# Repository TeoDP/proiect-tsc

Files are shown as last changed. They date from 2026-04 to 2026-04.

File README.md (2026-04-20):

# InkTime Smartwatch PCB

## General Description

This project involves the development of a PCB for an open-source smartwatch named InkTime, based on the nRF52840 microcontroller. The primary goal was to integrate all necessary components, including processing, sensors, power management, and user interface, onto a compact board that adheres to both electrical constraints and the mechanical limitations of the device housing.

The design was created using Fusion 360 Electronics, following the provided electrical schematics and laboratory layout guidelines. Significant emphasis was placed on precise routing, ground plane integrity, and component density within a limited footprint.

## Hardware Components

The system's core components include:

    - nRF52840: Main microcontroller with BLE capabilities.

    - IMU: Accelerometer and Gyroscope for motion tracking.

    - E-Paper Display: Ultra-low-power visual interface.

    - PMIC: Power Management IC for system stability.

    - Li-Po Battery: System power source.

    - USB-C: Interface for charging and power supply.

    - Haptic Motor: Vibration feedback.

Component Connectivity:

    - IMU: Connected to the MCU via I2C (SDA, SCL).

    - Display: Connected via SPI (MOSI, SCK, CS, DC, RST).

    - PMIC: Manages the entire system's power distribution.

    - USB-C: Connected directly to the charging circuitry.

    - Haptic Motor: Controlled via standard GPIO.

## Hardware Functionality

The system is centered around the nRF52840, which manages all peripherals and communications. Communication with sensors and the display is handled through standard interfaces:

    - SPI: Utilized for the display to ensure higher data transfer speeds.

    - I2C: Utilized for the IMU for simple and efficient sensor polling.

The system is powered by a Li-Po battery via a PMIC circuit that provides:

    - Voltage stabilization.

    - Overcharge/discharge protection.

    - Power distribution across all subsystems.

USB-C serves a dual purpose for battery charging and direct system power. The haptic motor provides tactile feedback and is managed by a dedicated GPIO pin.

### Estimated Consumption:

    - MCU: Low consumption in sleep mode, higher during active BLE transmission.

    - E-Paper Display: Negligible consumption (only draws power during screen updates).

    - IMU: Low power consumption over I2C.

## PCB Layout

### The PCB was designed using a 2-layer stackup:

    - Top Layer: Primary component placement and signal routing.

    - Bottom Layer: Supplementary routing and dedicated ground plane.

### Design Rules Applied:

    - Power Traces: Increased width for power lines (e.g., 3V3, VBUS).

    - Signal Traces: Minimum width of 0.15 mm.

    - Geometry: Avoided 90-degree angles to prevent signal reflection and manufacturing issues.

### Antenna Design:

    - Copper-free zone maintained directly beneath the antenna.

    - No routing allowed in the antenna keepout area to ensure signal integrity.

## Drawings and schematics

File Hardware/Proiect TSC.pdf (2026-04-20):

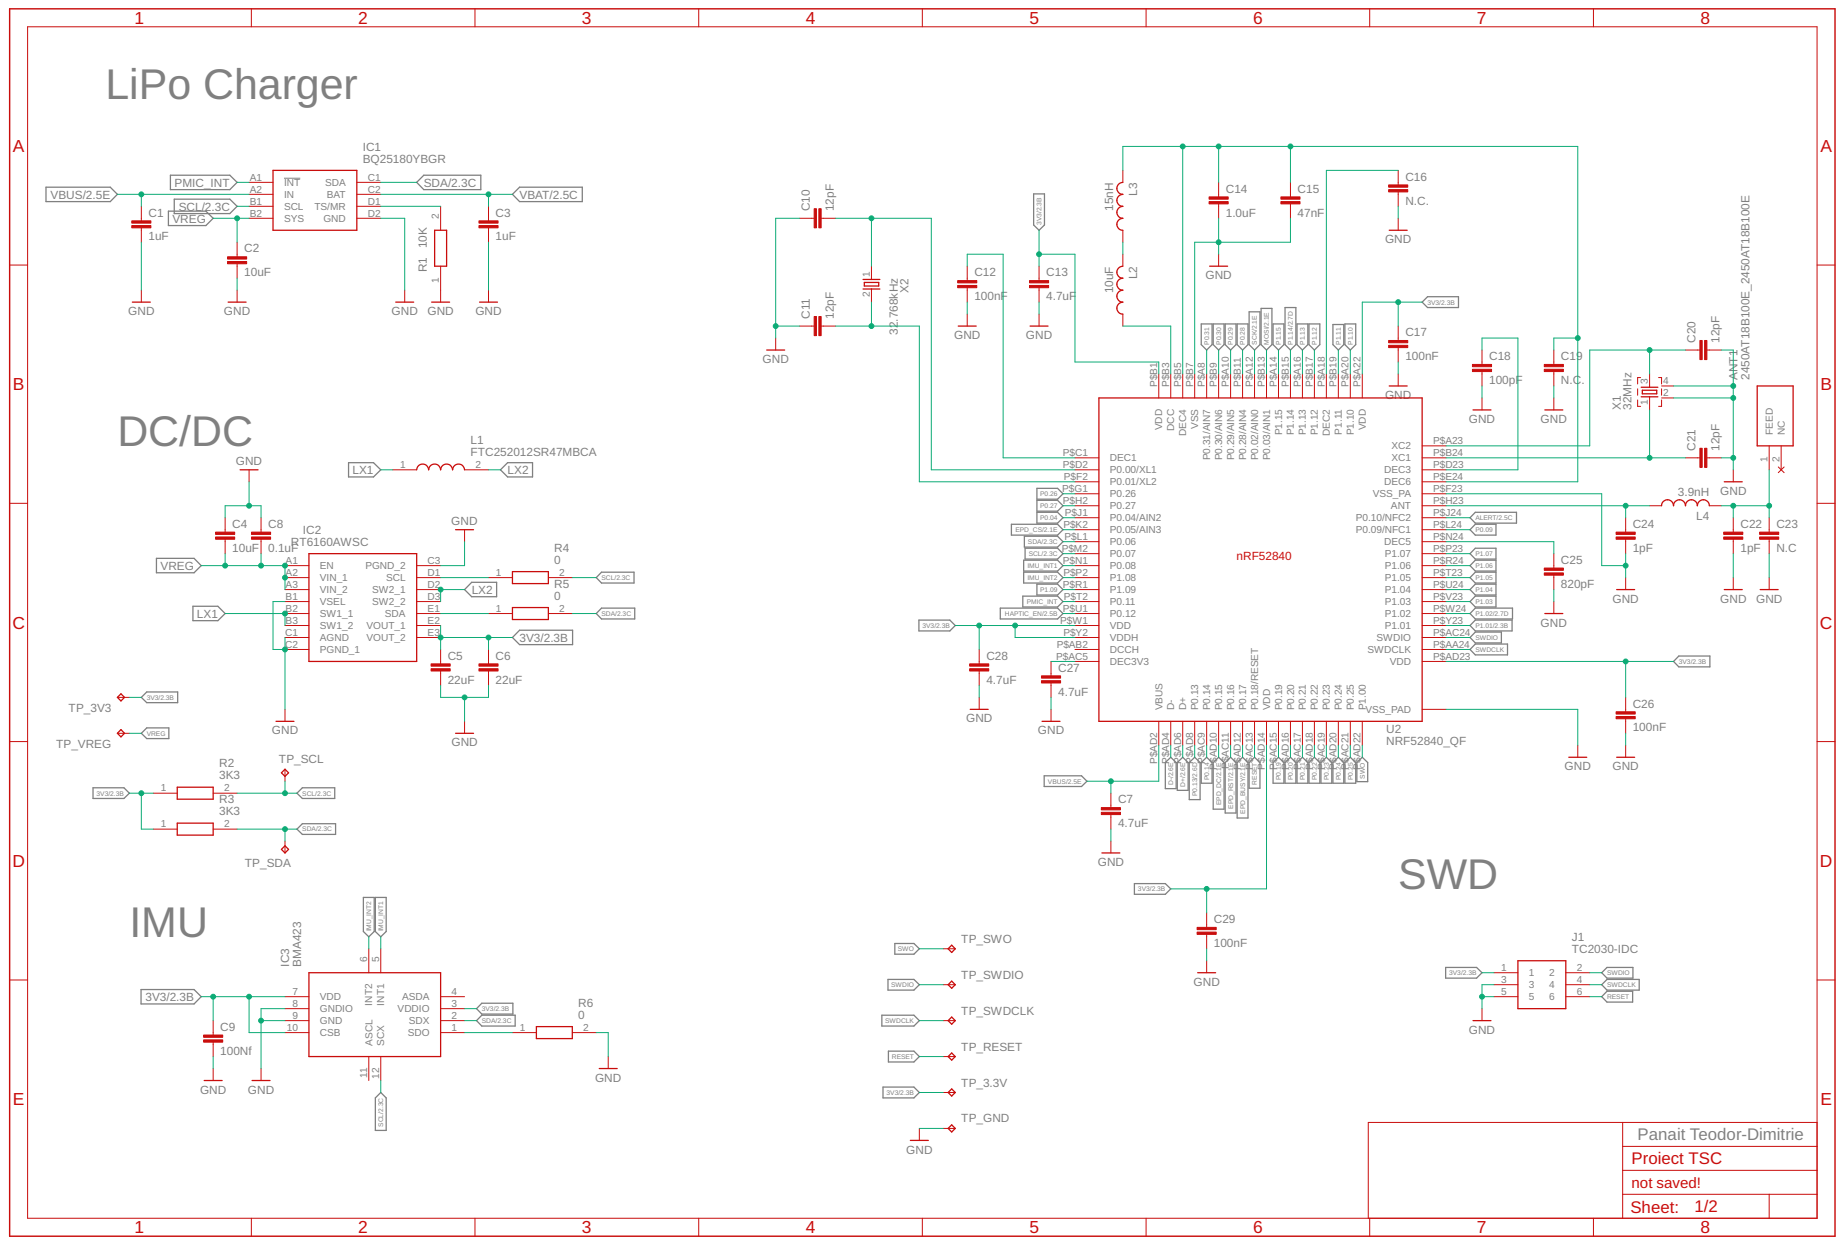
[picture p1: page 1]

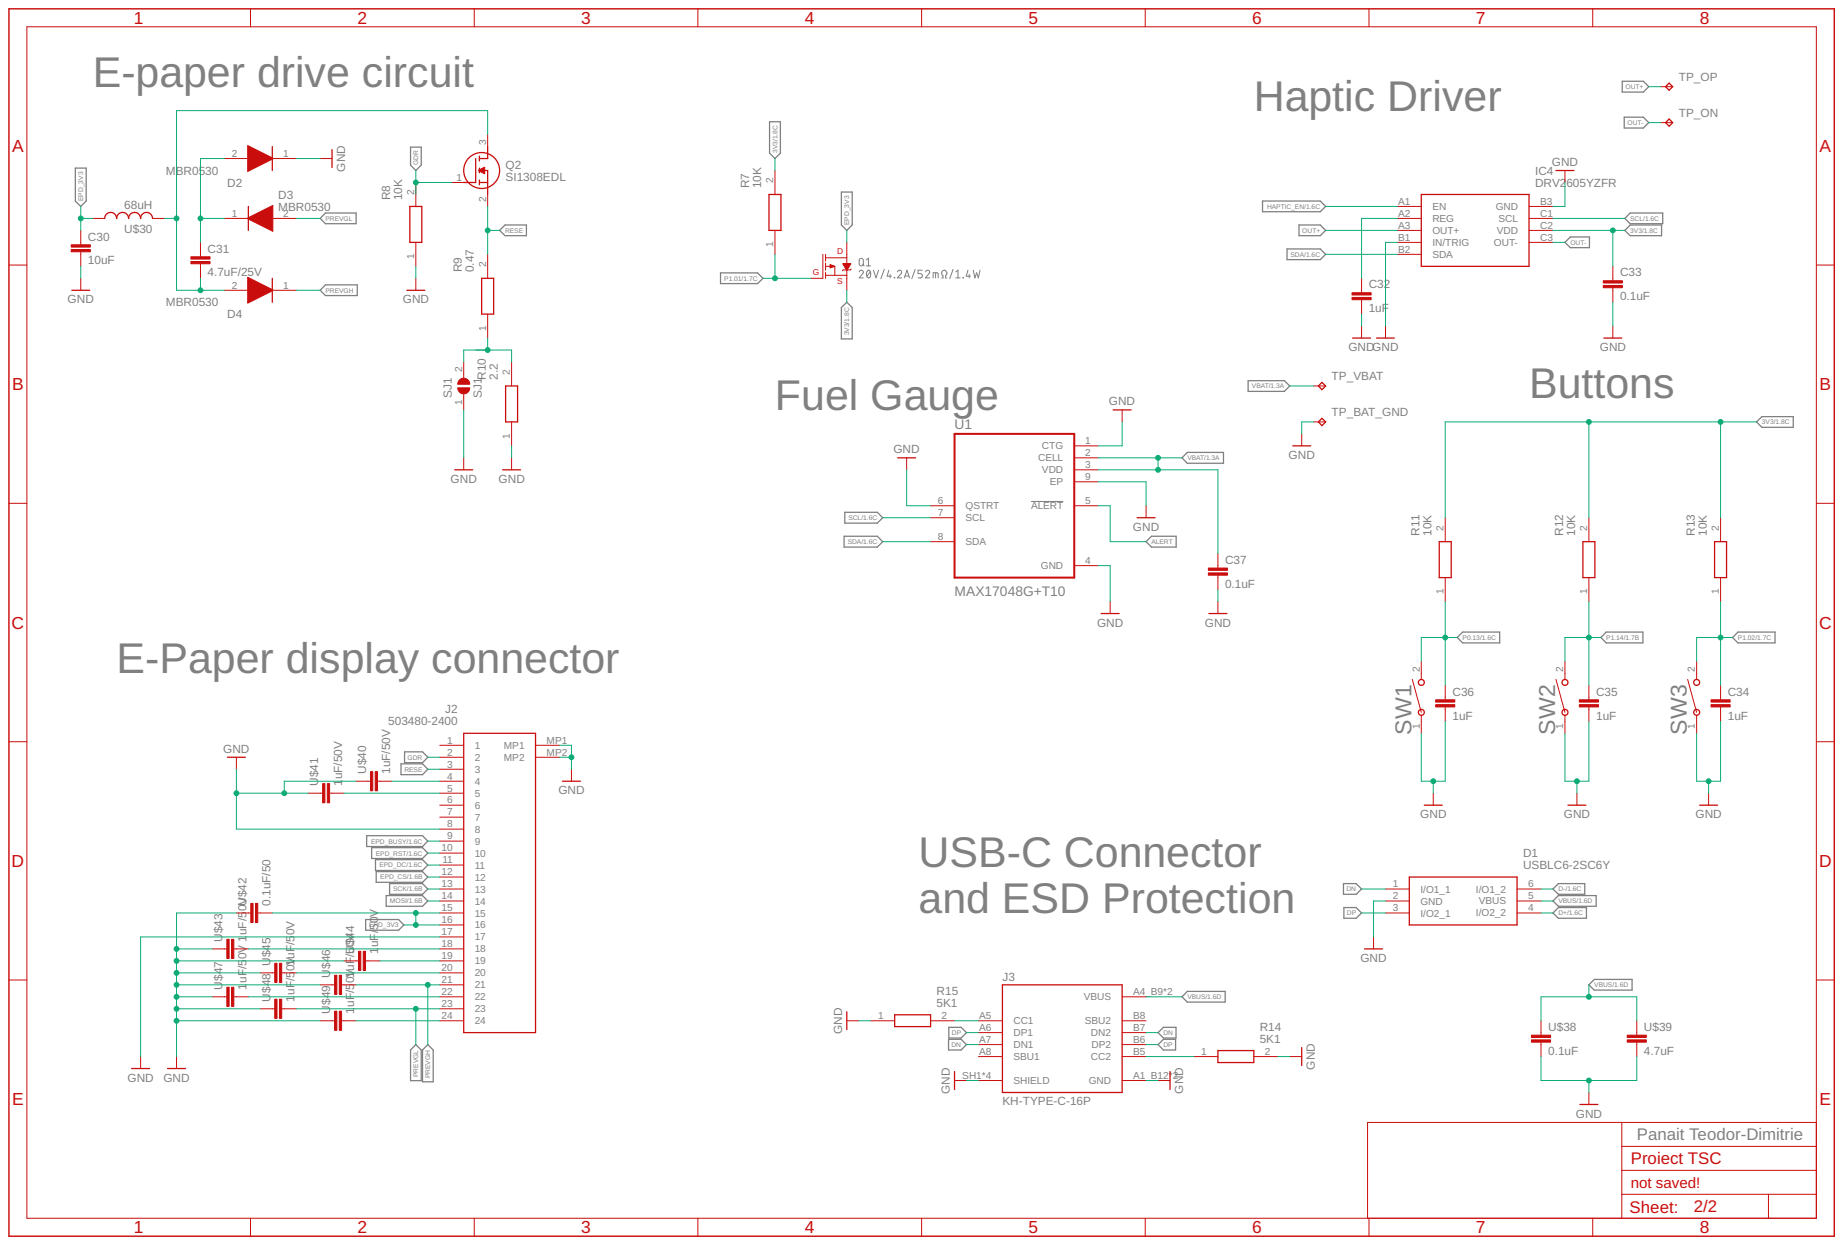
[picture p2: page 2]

EPD_3V3 | 16

18
19

23
24

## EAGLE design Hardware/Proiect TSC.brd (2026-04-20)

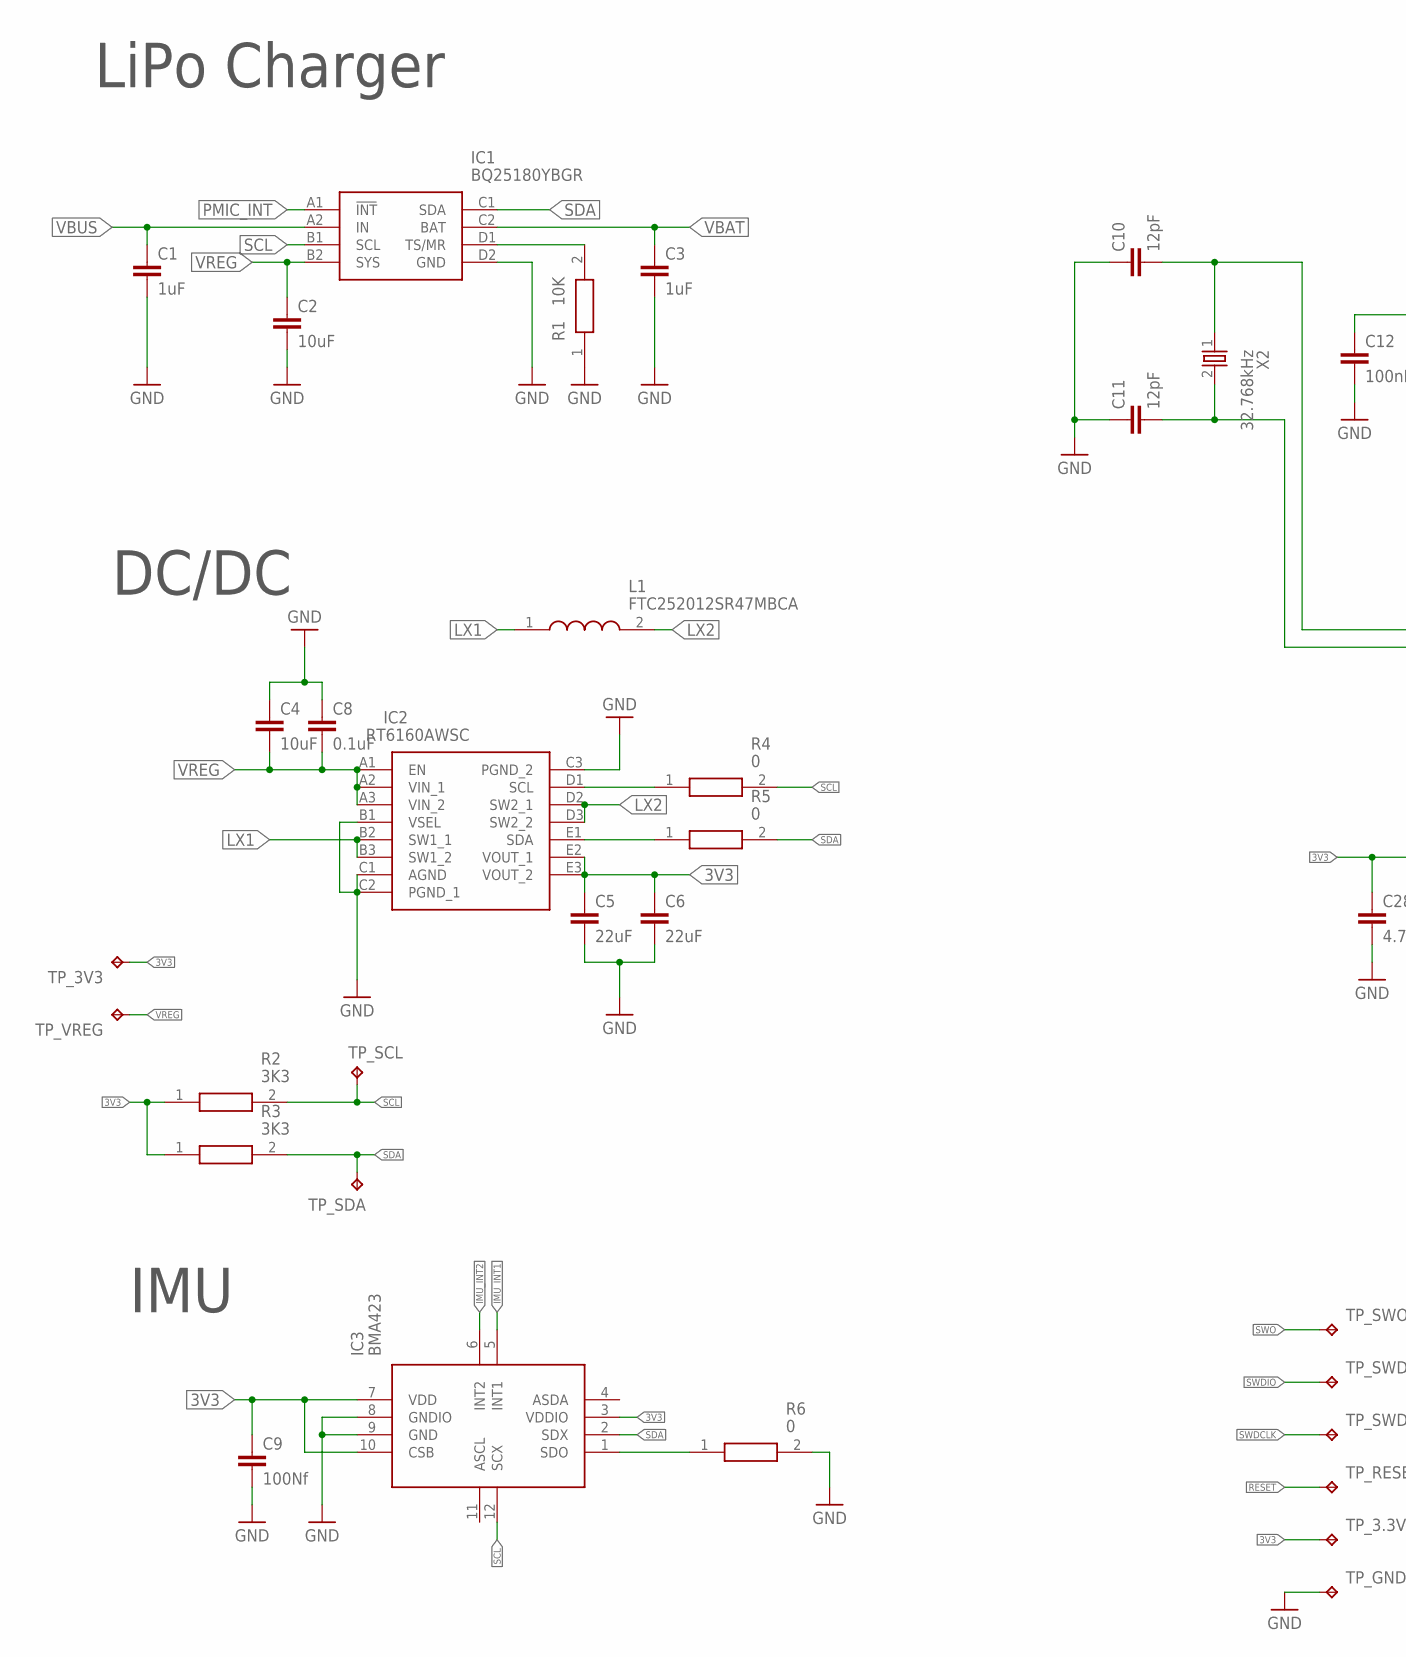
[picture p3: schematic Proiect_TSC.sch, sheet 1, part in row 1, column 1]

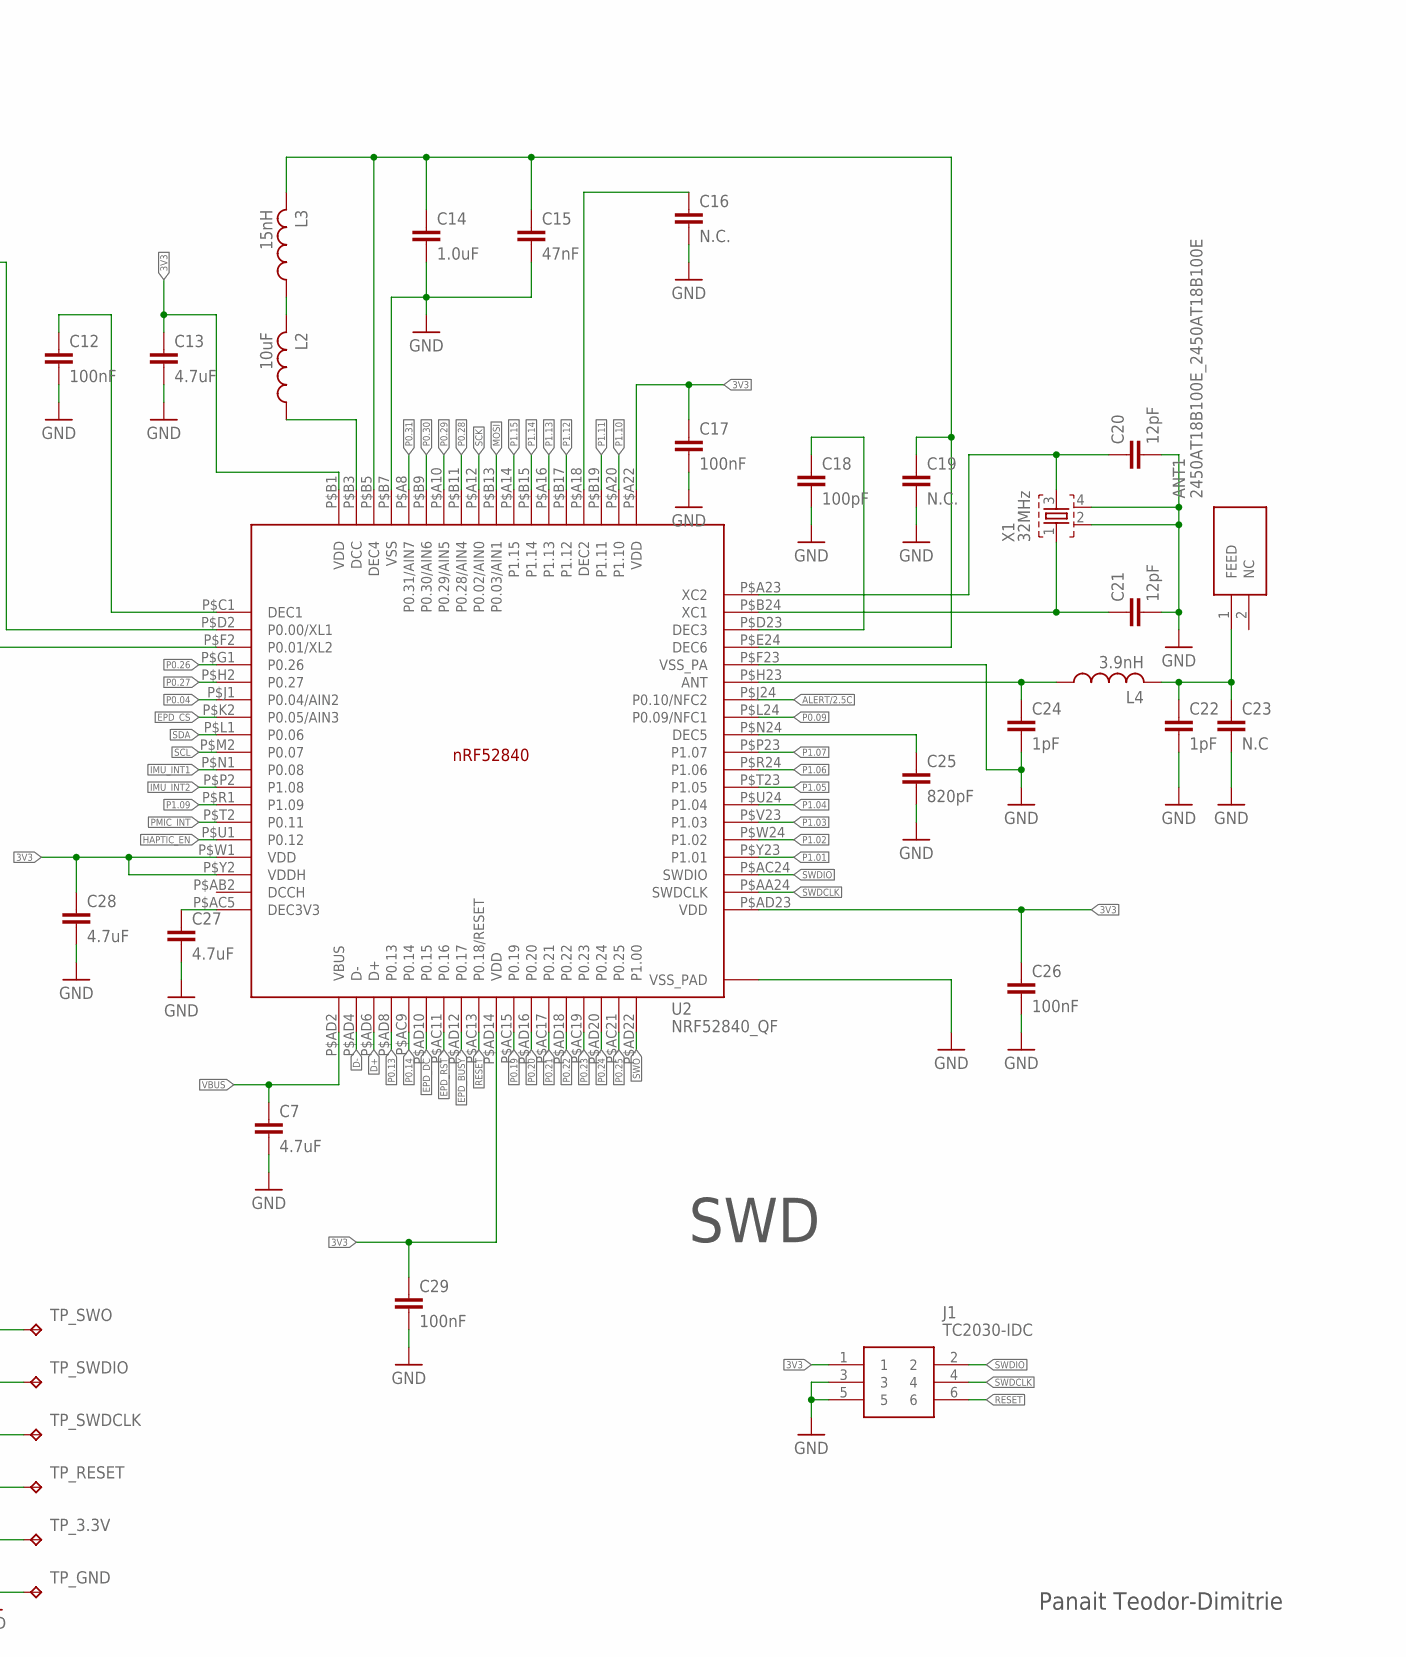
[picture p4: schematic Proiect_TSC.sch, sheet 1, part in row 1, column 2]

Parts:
ANT1: 2450AT18B100E_2450AT18B100E; 2450AT18B100E_ANTC3216X140N
C1, C3: 1uF; PERFECT_0402_0402
C2, C4: 10uF; PERFECT_0402_0402
C5, C6: 22uF; PERFECT_0402_0402
C7: 4.7uF; PERFECT_0402_0402
C8: 0.1uF; NORDIC_NRF_3_RESC0201_L
C9: 100Nf; NORDIC_NRF_3_RESC0201_L
C10, C11, C20, C21: 12pF; NORDIC_NRF_3_RESC0201_L
C12, C17, C26, C29: 100nF; NORDIC_NRF_3_RESC0201_L
C13, C27, C28: 4.7uF; NORDIC_NRF_3_RESC0402_L
C14: 1.0uF; NORDIC_NRF_3_RESC0402_L
C15: 47nF; NORDIC_NRF_3_RESC0201_L
C16, C19: N.C.; NORDIC_NRF_3_RESC0201_L
C18: 100pF; NORDIC_NRF_3_RESC0201_L
C22, C24: 1pF; NORDIC_NRF_3_RESC0201_L
C23: N.C; NORDIC_NRF_3_RESC0201_L
C25: 820pF; NORDIC_NRF_3_RESC0201_L
IC1: BQ25180YBGR; BQ25180YBGR_BGA8C40P2X4_100X155X50
IC2: RT6160AWSC; RT6160AWSC_BGA15C40P3X5_140X230X60
IC3: BMA423; BMA423_BMA423
J1: TC2030-IDC; TC2030-IDC_TC2030IDC
L1: FTC252012SR47MBCA; MLP2016SR47MT0S1_INDC2016X100N
L2: 10uF; NORDIC_NRF_2_RESC0201_L
L3: 15nH; NORDIC_NRF_2_RESC0201_L
L4: 3.9nH; NORDIC_NRF_2_RESC0201_L
R1: 10K; CPF0201D7K68C1_0201
R2, R3: 3K3; CPF0201D7K68C1_0201
R4, R5, R6: 0; CPF0201D7K68C1_0201
TP_3.3V, TP_3V3: HECTOR_WATCH_1_TPTP20R; HECTOR_WATCH_1_TP20R
TP_GND: HECTOR_WATCH_1_TPTP20R; HECTOR_WATCH_1_TP20R
TP_RESET: HECTOR_WATCH_1_TPTP20R; HECTOR_WATCH_1_TP20R
TP_SCL: HECTOR_WATCH_1_TPTP20R; HECTOR_WATCH_1_TP20R
TP_SDA: HECTOR_WATCH_1_TPTP20R; HECTOR_WATCH_1_TP20R
TP_SWDCLK: HECTOR_WATCH_1_TPTP20R; HECTOR_WATCH_1_TP20R
TP_SWDIO: HECTOR_WATCH_1_TPTP20R; HECTOR_WATCH_1_TP20R
TP_SWO: HECTOR_WATCH_1_TPTP20R; HECTOR_WATCH_1_TP20R
TP_VREG: HECTOR_WATCH_1_TPTP20R; HECTOR_WATCH_1_TP20R
U2: NRF52840_QF; NORDIC_NRF_4_AQFN50P700X700X85_HS-74N
X1: 32MHz; NORDIC_NRF_BT-XTAL_2016_N
X2: 32.768kHz; NORDIC_NRF_1_XTAL_3215_N

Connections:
3V3: C5.1, C6.1, C9.1, C13.1, C17.1, C26.1, C28.1, C29.1, IC2.E2 (VOUT_1), IC2.E3 (VOUT_2), IC3.3 (VDDIO), IC3.7 (VDD), IC3.10 (CSB), J1.1, R2.1, R3.1, TP_3.3V.TP, TP_3V3.TP, U2.P$A22 (VDD), U2.P$AD14 (VDD), U2.P$AD23 (VDD), U2.P$B1 (VDD), U2.P$W1 (VDD), U2.P$Y2 (VDDH); also elsewhere on the board
ALERT/2.5C: U2.P$J24 (P0.10/NFC2)
D+: U2.P$AD6 (D+); also elsewhere on the board
D-: U2.P$AD4 (D-); also elsewhere on the board
EPD_BUSY: U2.P$AD12 (P0.17); also elsewhere on the board
EPD_CS: U2.P$K2 (P0.05/AIN3); also elsewhere on the board
EPD_DC: U2.P$AD10 (P0.15); also elsewhere on the board
EPD_RST: U2.P$AC11 (P0.16); also elsewhere on the board
GND: C1.2, C2.2, C3.2, C4.1, C5.2, C6.2, C7.2, C8.1, C9.2, C10.1, C11.1, C12.2, C13.2, C14.2, C15.2, C16.2, C17.2, C18.2, C19.2, C20.2, C21.2, C22.2, C23.2, C24.2, C25.2, C26.2, C27.2, C28.2, C29.2, IC1.D2 (GND), IC2.B1 (VSEL), IC2.C1 (AGND), IC2.C2 (PGND_1), IC2.C3 (PGND_2), IC3.8 (GNDIO), IC3.9 (GND), J1.3, J1.5, R1.1, R6.2, TP_GND.TP, U2.P$74 (VSS_PAD), U2.P$75 (VSS_PAD), U2.P$76 (VSS_PAD), U2.P$77 (VSS_PAD), U2.P$78 (VSS_PAD), U2.P$79 (VSS_PAD), U2.P$80 (VSS_PAD), U2.P$81 (VSS_PAD), U2.P$82 (VSS_PAD), U2.P$83 (VSS_PAD), U2.P$84 (VSS_PAD), U2.P$85 (VSS_PAD), U2.P$86 (VSS_PAD), U2.P$87 (VSS_PAD), U2.P$88 (VSS_PAD), U2.P$89 (VSS_PAD), U2.P$90 (VSS_PAD), U2.P$B7 (VSS), U2.P$F23 (VSS_PA), X1.2, X1.4; also elsewhere on the board
HAPTIC_EN: U2.P$U1 (P0.12); also elsewhere on the board
IMU_INT1: IC3.5 (INT1), U2.P$N1 (P0.08)
IMU_INT2: IC3.6 (INT2), U2.P$P2 (P1.08)
LX1: IC2.B2 (SW1_1), IC2.B3 (SW1_2), L1.1
LX2: IC2.D2 (SW2_1), IC2.D3 (SW2_2), L1.2
MOSI: U2.P$B13 (P0.03/AIN1); also elsewhere on the board
unnamed: ANT1.1 (FEED), C22.1, C23.1, L4.2
unnamed: IC1.D1 (TS/MR), R1.2
unnamed: C20.1, U2.P$A23 (XC2), X1.3
unnamed: IC2.D1 (SCL), R4.1
unnamed: C12.1, U2.P$C1 (DEC1)
unnamed: IC2.E1 (SDA), R5.1
unnamed: C10.2, U2.P$D2 (P0.00/XL1), X2.1
unnamed: C11.2, U2.P$F2 (P0.01/XL2), X2.2
unnamed: IC3.1 (SDO), R6.1
unnamed: L2.2, L3.1
unnamed: C14.1, C15.1, C19.1, L3.2, U2.P$B5 (DEC4), U2.P$E24 (DEC6)
unnamed: C21.1, U2.P$B24 (XC1), X1.1
unnamed: L2.1, U2.P$B3 (DCC)
unnamed: C18.1, U2.P$D23 (DEC3)
unnamed: C24.1, L4.1, U2.P$H23 (ANT)
unnamed: C27.1, U2.P$AC5 (DEC3V3)
unnamed: C25.1, U2.P$N24 (DEC5)
unnamed: C16.1, U2.P$A18 (DEC2)
P0.04: U2.P$J1 (P0.04/AIN2)
P0.09: U2.P$L24 (P0.09/NFC1)
P0.13: U2.P$AD8 (P0.13); also elsewhere on the board
P0.14: U2.P$AC9 (P0.14)
P0.19: U2.P$AC15 (P0.19)
P0.20: U2.P$AD16 (P0.20)
P0.21: U2.P$AC17 (P0.21)
P0.22: U2.P$AD18 (P0.22)
P0.23: U2.P$AC19 (P0.23)
P0.24: U2.P$AD20 (P0.24)
P0.25: U2.P$AC21 (P0.25)
P0.26: U2.P$G1 (P0.26)
P0.27: U2.P$H2 (P0.27)
P0.28: U2.P$B11 (P0.28/AIN4)
P0.29: U2.P$A10 (P0.29/AIN5)
P0.30: U2.P$B9 (P0.30/AIN6)
P0.31: U2.P$A8 (P0.31/AIN7)
P1.01: U2.P$Y23 (P1.01); also elsewhere on the board
P1.02: U2.P$W24 (P1.02); also elsewhere on the board
P1.03: U2.P$V23 (P1.03)
P1.04: U2.P$U24 (P1.04)
P1.05: U2.P$T23 (P1.05)
P1.06: U2.P$R24 (P1.06)
P1.07: U2.P$P23 (P1.07)
P1.09: U2.P$R1 (P1.09)
P1.10: U2.P$A20 (P1.10)
P1.11: U2.P$B19 (P1.11)
P1.12: U2.P$B17 (P1.12)
P1.13: U2.P$A16 (P1.13)
P1.14: U2.P$B15 (P1.14); also elsewhere on the board
P1.15: U2.P$A14 (P1.15)
PMIC_INT: IC1.A1 (!INT), U2.P$T2 (P0.11)
RESET: J1.6, TP_RESET.TP, U2.P$AC13 (P0.18/RESET)
SCK: U2.P$A12 (P0.02/AIN0); also elsewhere on the board
SCL: IC1.B1 (SCL), IC3.12 (SCX), R2.2, R4.2, TP_SCL.TP, U2.P$M2 (P0.07); also elsewhere on the board
SDA: IC1.C1 (SDA), IC3.2 (SDX), R3.2, R5.2, TP_SDA.TP, U2.P$L1 (P0.06); also elsewhere on the board
SWDCLK: J1.4, TP_SWDCLK.TP, U2.P$AA24 (SWDCLK)
SWDIO: J1.2, TP_SWDIO.TP, U2.P$AC24 (SWDIO)
SWO: TP_SWO.TP, U2.P$AD22 (P1.00)
VBAT: C3.1, IC1.C2 (BAT); also elsewhere on the board
VBUS: C1.1, C7.1, IC1.A2 (IN), U2.P$AD2 (VBUS); also elsewhere on the board
VREG: C2.1, C4.2, C8.2, IC1.B2 (SYS), IC2.A1 (EN), IC2.A2 (VIN_1), IC2.A3 (VIN_2), TP_VREG.TP

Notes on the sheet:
LiPo Charger
DC/DC
IMU
SWD
Panait Teodor-Dimitrie

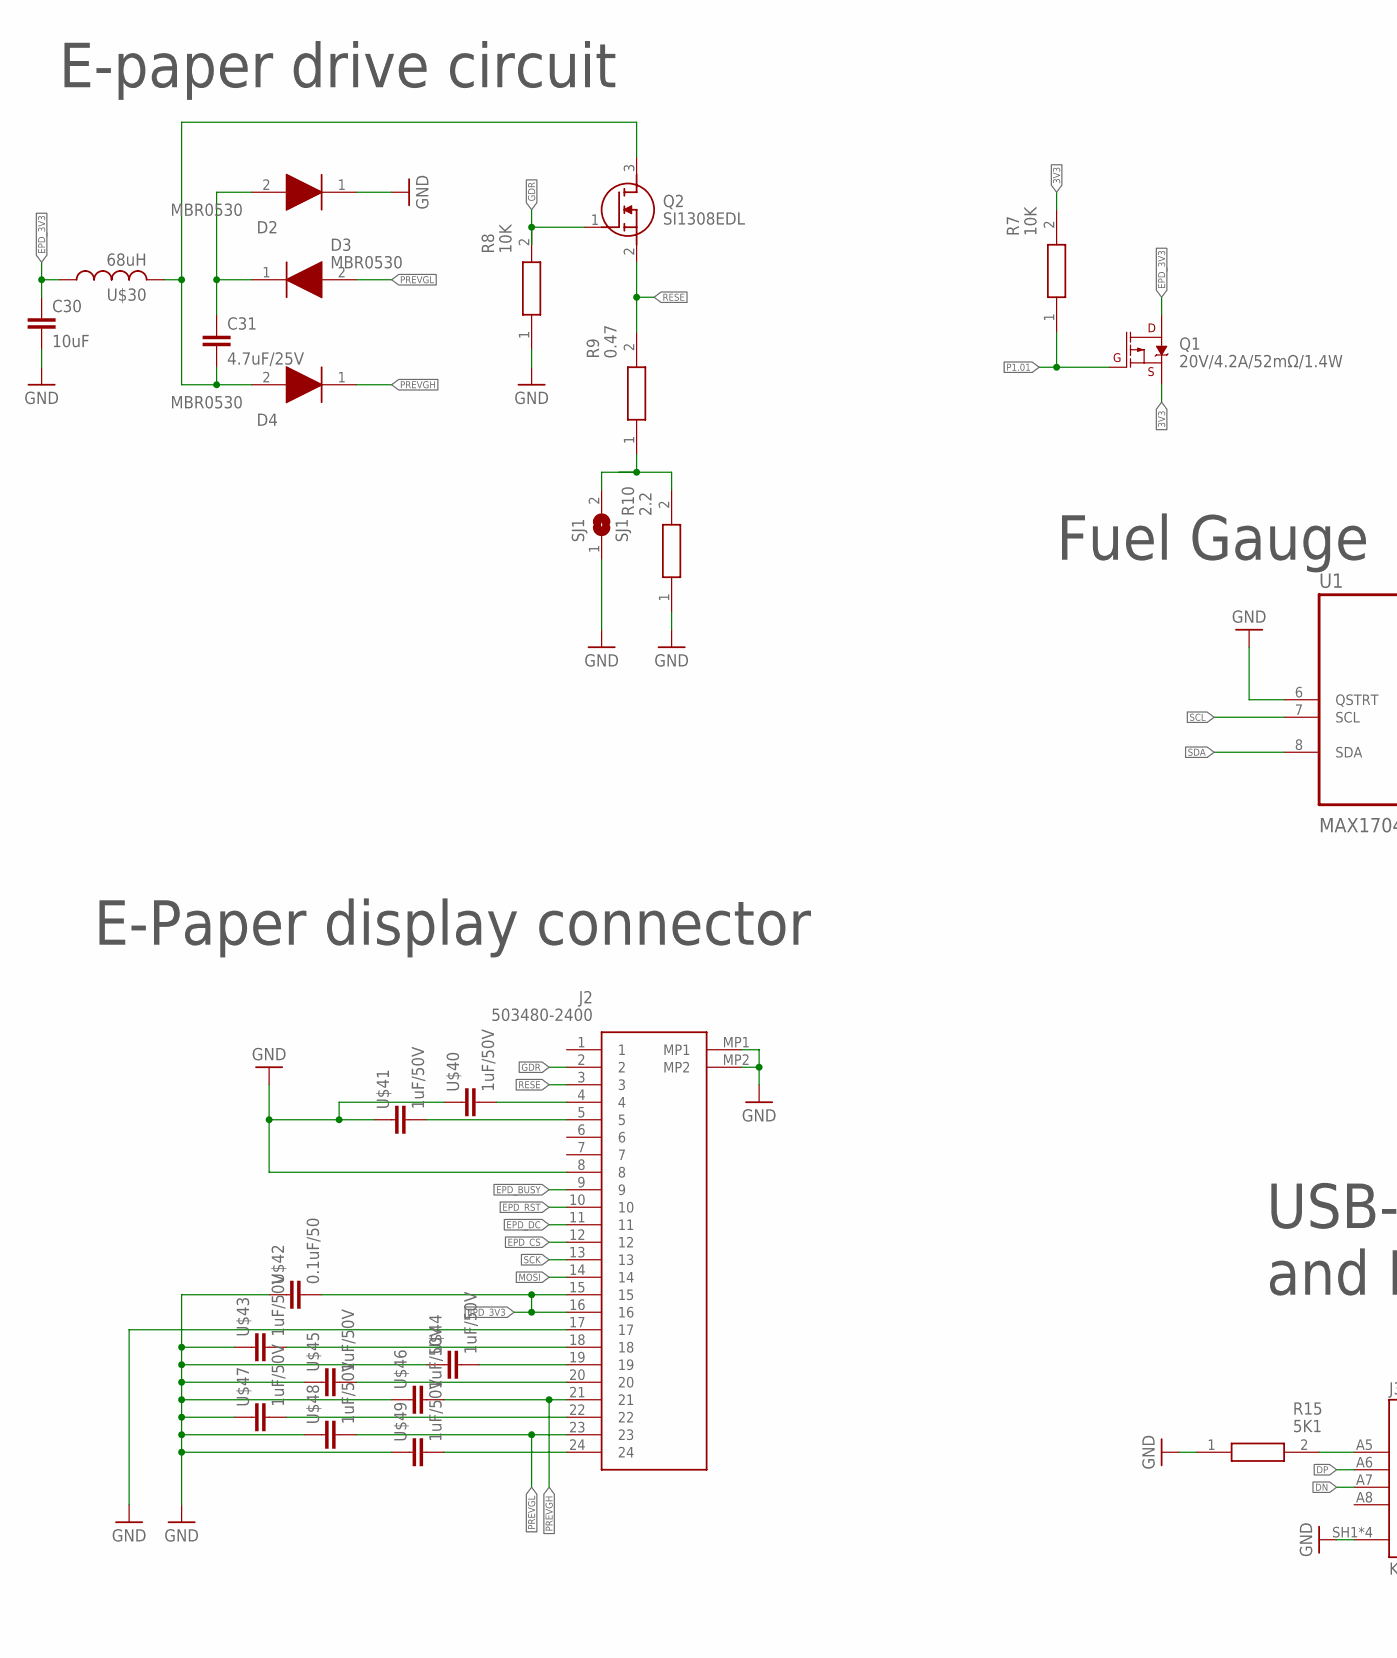
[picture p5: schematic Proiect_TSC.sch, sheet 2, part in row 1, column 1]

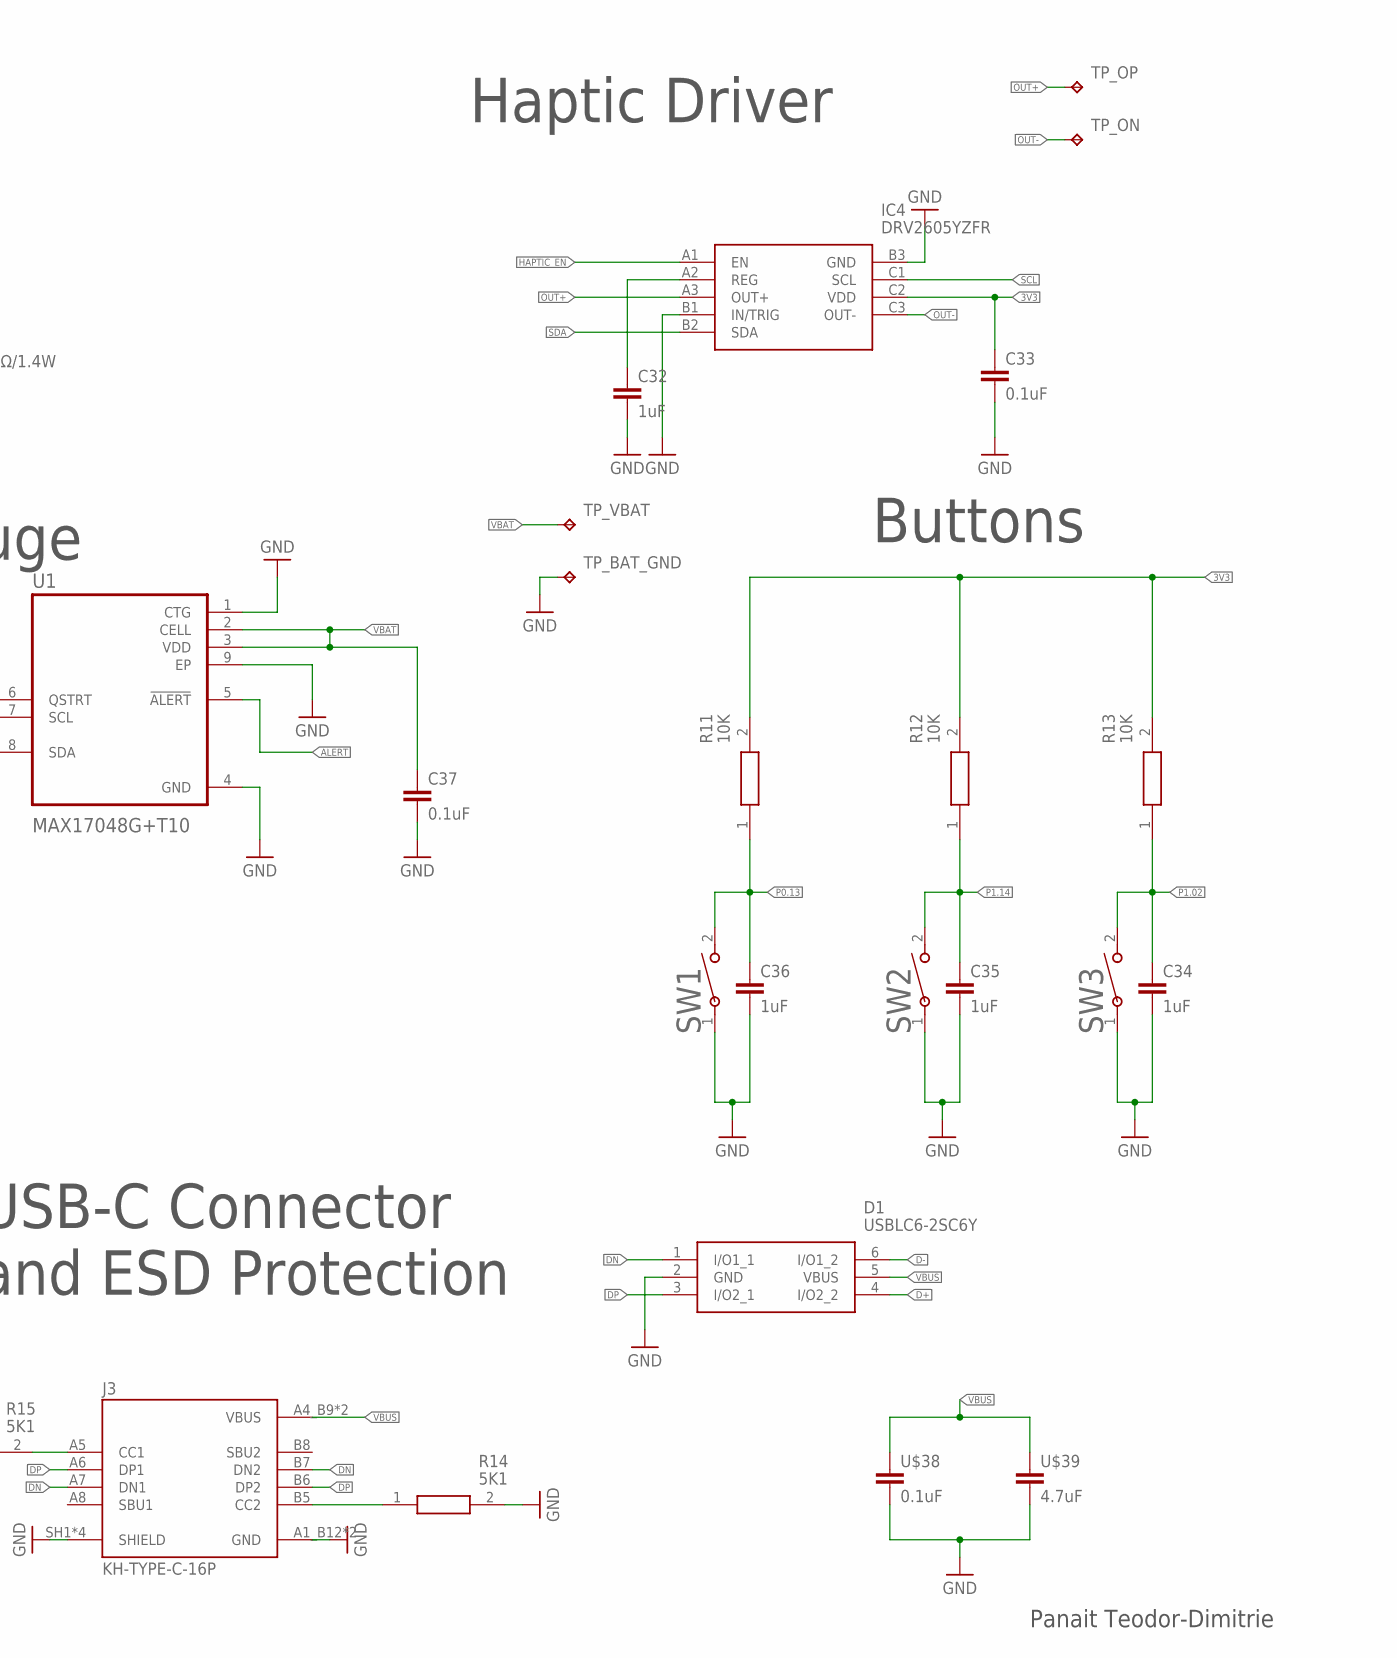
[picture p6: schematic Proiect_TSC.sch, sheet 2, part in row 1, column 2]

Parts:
C30: 10uF; NORDIC_NRF_3_RESC0402_L
C31: 4.7uF/25V; NORDIC_NRF_3_RESC0402_L
C32, C34, C35, C36: 1uF; NORDIC_NRF_3_RESC0402_L
C33, C37: 0.1uF; NORDIC_NRF_3_RESC0201_L
D1: USBLC6-2SC6Y; ESP32_C6_LIBRARY_3_SOT95P280X145-6N
D2, D3, D4: MBR0530; ESP32_C6_LIBRARY_5_SOD3716X135N
IC4: DRV2605YZFR; DRV2605YZFR_BGA9C50P3X3_144X144X62
J2: 503480-2400; 503480-2400_5034802400
J3: KH-TYPE-C-16P; KH-TYPE-C-16P_KINGHELM_KH-TYPE-C-16P
Q1: 20V/4.2A/52mΩ/1.4W; ESP32_C6_LIBRARY_4_ESP32_C6_LIBRARY_4_ESP32_C6_LIBRARY_4_ES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
Q2: SI1308EDL; ESP32_C6_LIBRARY_6_SOT65P210X110-3N
R7, R8, R11, R12, R13: 10K; CPF0201D7K68C1_0201
R9: 0.47; CPF0201D7K68C1_0201
R10: 2.2; CPF0201D7K68C1_0201
R14, R15: 5K1; CPF0201D7K68C1_0201
SJ1: SJ1; ESP32_C6_LIBRARY_7_JUMPER_SJ
SW1: SW1; 2025-10-22_07-23-44_LIBRARY_SW_EVP-AKE31A_PAN
SW2, SW3: 2025-10-22_07-23-44_LIBRARY_EVP-AKE31ASW_EVP-AKE3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; 2025-10-22_07-23-44_LIBRARY_SW_EVP-AKE31A_PAN
TP_BAT_GND: HECTOR_WATCH_1_TPTP20R; HECTOR_WATCH_1_TP20R
TP_ON: HECTOR_WATCH_1_TPTP20R; HECTOR_WATCH_1_TP20R
TP_OP: HECTOR_WATCH_1_TPTP20R; HECTOR_WATCH_1_TP20R
TP_VBAT: HECTOR_WATCH_1_TPTP20R; HECTOR_WATCH_1_TP20R
U1: MAX17048G+T10; ESP32_C6_LIBRARY_SON50P200X200X80-9N
U$30: 68uH; NORDIC_NRF_2_RESC0201_L
U$38: 0.1uF; NORDIC_NRF_3_RESC0201_L
U$39: 4.7uF; NORDIC_NRF_3_RESC0402_L
U$40, U$41, U$43, U$44, U$45, U$46, U$47, U$48, U$49: 1uF/50V; NORDIC_NRF_3_RESC0402_L
U$42: 0.1uF/50; NORDIC_NRF_3_RESC0201_L

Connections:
3V3: C33.1, IC4.C2 (VDD), Q1.2 (S), R7.2, R11.2, R12.2, R13.2; also elsewhere on the board
ALERT: U1.5 (!ALERT)
D+: D1.4 (I/O2_2); also elsewhere on the board
D-: D1.6 (I/O1_2); also elsewhere on the board
DN: D1.1 (I/O1_1), J3.A7 (DN1), J3.B7 (DN2)
DP: D1.3 (I/O2_1), J3.A6 (DP1), J3.B6 (DP2)
EPD_3V3: C30.1, J2.15, J2.16, Q1.3 (D), U$30.1, U$42.2
EPD_BUSY: J2.9; also elsewhere on the board
EPD_CS: J2.12; also elsewhere on the board
EPD_DC: J2.11; also elsewhere on the board
EPD_RST: J2.10; also elsewhere on the board
GDR: J2.2, Q2.1 (G), R8.2
GND: C30.2, C32.2, C33.2, C34.2, C35.2, C36.2, C37.2, D1.2 (GND), D2.1 (K), IC4.B1 (IN/TRIG), IC4.B3 (GND), J2.8, J2.17, J2.MP1, J2.MP2, J3.A1_B12 (GND), J3.A12_B1 (GND), J3.SH1 (SHIELD), J3.SH2 (SHIELD), J3.SH3 (SHIELD), J3.SH4 (SHIELD), R8.1, R10.1, R14.2, R15.1, SJ1.1, SW1.1, SW2.1, SW3.1, TP_BAT_GND.TP, U1.1 (CTG), U1.4 (GND), U1.6 (QSTRT), U1.9 (EP), U$38.2, U$39.2, U$40.1, U$41.1, U$42.1, U$43.1, U$44.1, U$45.1, U$46.1, U$47.1, U$48.1, U$49.1; also elsewhere on the board
HAPTIC_EN: IC4.A1 (EN); also elsewhere on the board
MOSI: J2.14; also elsewhere on the board
unnamed: C31.1, D2.2 (A), D3.1 (K)
unnamed: C31.2, D4.2 (A), Q2.3 (D), U$30.2
unnamed: C32.1, IC4.A2 (REG)
unnamed: J2.4, U$40.2
unnamed: J2.5, U$41.2
unnamed: J3.A5 (CC1), R15.2
unnamed: R9.1, R10.2, SJ1.2
unnamed: J2.18, U$43.2
unnamed: J2.19, U$44.2
unnamed: J2.20, U$45.2
unnamed: J2.22, U$47.2
unnamed: J2.24, U$49.2
unnamed: J3.B5 (CC2), R14.1
OUT+: IC4.A3 (OUT+), TP_OP.TP
OUT-: IC4.C3 (OUT-), TP_ON.TP
P0.13: C36.1, R11.1, SW1.2; also elsewhere on the board
P1.01: Q1.1 (G), R7.1; also elsewhere on the board
P1.02: C34.1, R13.1, SW3.2; also elsewhere on the board
P1.14: C35.1, R12.1, SW2.2; also elsewhere on the board
PREVGH: D4.1 (K), J2.21, U$46.2
PREVGL: D3.2 (A), J2.23, U$48.2
RESE: J2.3, Q2.2 (S), R9.2
SCK: J2.13; also elsewhere on the board
SCL: IC4.C1 (SCL), U1.7 (SCL); also elsewhere on the board
SDA: IC4.B2 (SDA), U1.8 (SDA); also elsewhere on the board
VBAT: C37.1, TP_VBAT.TP, U1.2 (CELL), U1.3 (VDD); also elsewhere on the board
VBUS: D1.5 (VBUS), J3.A4_B9 (VBUS), J3.A9_B4 (VBUS), U$38.1, U$39.1; also elsewhere on the board

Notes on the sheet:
E-paper drive circuit
Fuel Gauge
Haptic Driver
E-Paper display connector
Buttons
USB-C Connector and ESD Protection
Panait Teodor-Dimitrie

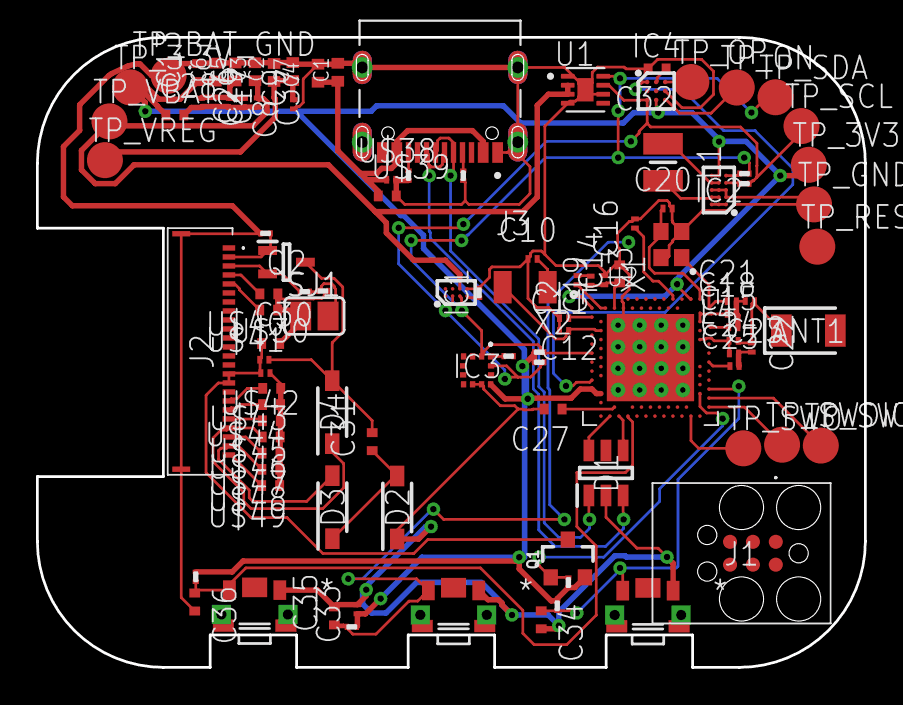
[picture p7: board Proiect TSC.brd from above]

Board: 2 copper layers, 46.0 x 35.0 mm, 105 parts (0 on the bottom side), 69 nets.

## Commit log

2026-04-15 Add .sch and .brd files
    First revision, many this still due to change
    [Proiect TSC.brd, Proiect_TSC.sch]
2026-04-20 WIP commit. Still adding features
    [Proiect TSC.brd, Proiect_TSC.sch]

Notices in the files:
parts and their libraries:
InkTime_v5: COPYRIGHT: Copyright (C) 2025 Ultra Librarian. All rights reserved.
